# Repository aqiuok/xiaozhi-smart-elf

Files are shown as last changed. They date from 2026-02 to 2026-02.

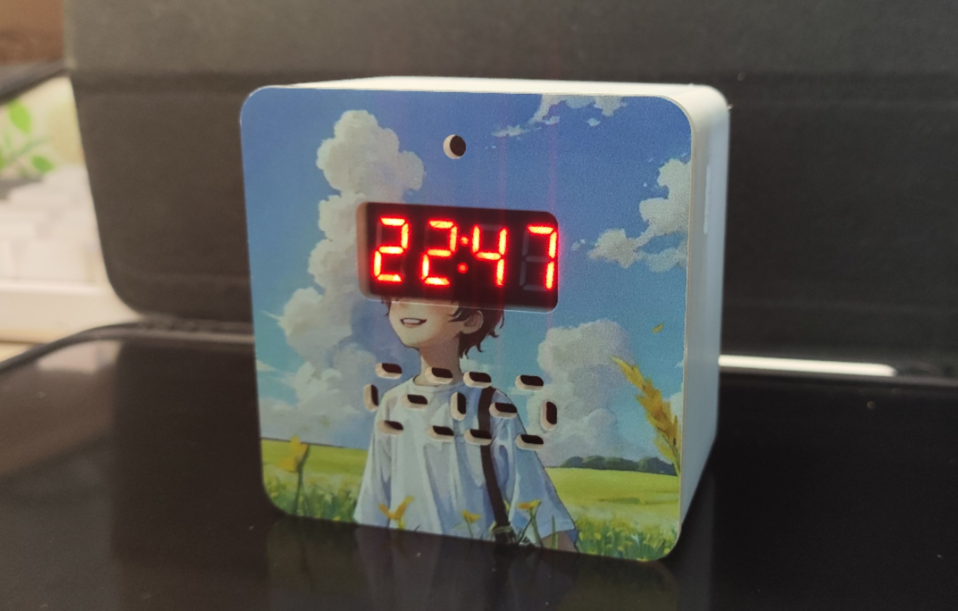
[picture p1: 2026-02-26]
photos/R5iOM2G0jZUlhVA9MYZS8TLprcBygYSpuvqxCEv5.jpeg

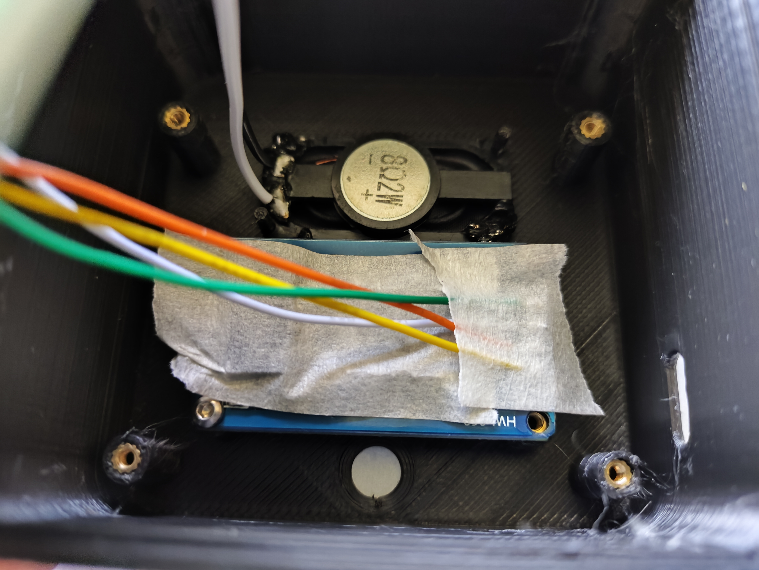
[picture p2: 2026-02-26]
photos/ceK1EityDw41dxoPptlsX2srFDPeEycVAjOOcUzq.jpeg

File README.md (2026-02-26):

### 小智精灵

##### 文件内容

小智精灵

				模块代码

								AnalogRead

								DS1302_Memory

								SimpleTime

								TM1637Test

								UART

				外壳

						小智精灵 v19.stl		（前壳）

						小智精灵 v21.stl		（后盖）

				总代码

								node1				（台灯）

								node2				（客厅灯）

								WiFiMeshv1_1  （小智精灵ESP32-C3）

								SU-03T			   （离线语音SU-03T烧录固件，烧录工具，烧录教程）

##### 	语音控制

微信截图_20230427223057						







##### 模块测试记录

光敏获取当前光照强度，其中使用ADC，

		光强：844（613mv）

		光弱：1850（1274mv）

		黑暗：4095（2853mv）

获取当前时间

						1.DS1302设置时间，其中使用到DS1302库   

数据格式：

```
10:37:50.813 -> data read (20) = "what time is it"
10:37:55.790 -> 04/11/2023 10:37:31 +
```

						2.获取网络时间，午夜12点更新时间并写入DS1302，写入前先检查是否获取到准确时间（与DS1302的时间进行对比，相差 10S内进行更新时间，否则不进行更新）    

 数据格式：

```
11:34:51.666 -> Tuesday, April 11 2023 11:34:53
```

网络时间的库获取到时间格式

```
getLocalTime(&timeinfo)；
timeinfo
```

DS1302获取时间的格式

```
RtcDateTime now = Rtc.GetDateTime();
now.Hour();
```

数码管显示，驱动芯片为TM1637，可以设置数码管的亮度，通过光敏控制此亮度

语音模块，SU-03T，通过串口来实现

```
PWM模式下，关闭电平翻转
开启：占空比100
关闭：占空比0
```

小爱同学发送的信息

```
21:27:29.147 -> MQTT接收到的主题：LED1002
21:27:29.147 -> on
21:27:29.147 -> #node1#on#

21:28:06.948 -> MQTT接收到的主题：LED1002
21:28:06.948 -> on#80
21:28:06.948 -> #node1#on#80#
```

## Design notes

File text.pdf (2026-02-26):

# 小智精灵 基于WiFi-Mesh技术的智能桌面助手

河南省青年科技人才创新创业大赛

目录

## 第 1 章 项目功能介绍

产品概述：小智精灵是一个使用Wi-Fi Mesh技术控制智能家居的桌面离线语音助手摆件。小 智精灵由于使用的是Wi-Fi Mesh技术，使得在离网时可以使用自身的语音功能进行控制智能 家居，在在网时可以通过Web、微信小程序、APP以及小爱同学进行控制，解决没有网络时无 法控制家里智能设备的痛点，同时使用应答流程来保证传输的指令得到有效的执行。小智精 灵自身带有LED灯、光敏传感器和数码管，可以通过语音来控制自身灯光，使用20KHz PWM调 光，更加护眼；数码管通过RTC时钟显示当前时间，同时使用光照传感器来智能调控数码管亮 的程度，保证数码管亮度显示温和。底部带有无线充电线圈，可以无感充电，使用更加方 便。亮点：超多设备接入，可以不接服务器使用，超安全！

（1）使用Wi-Fi Mesh技术，将智能设备通过Wi-Fi Mesh连接，多个设备只需一个设备接入网 络，减小路由器的开支。
（2）超级安全，在离网时使用，能够提供更高的安全，对不信任物联网设备安全的人提供更 急啊安全的方案。
（3）控制精准，通过应答流程来保证下达的指令都能够准确执行。 （4）多方式控制，Web、APP、微信小程序和其他物联网平台（如：小爱同学）。 （5）无网络时可以通过自带的离线语音功能来控制智能家居，无网络使用更加安全。 （6）数码管时钟显示，RTC时钟芯片保证时间准确，联网时或重启时自动校准时间。 （7）数码管的亮度根据环境来调节，显示更加柔和。
（8）无线供电，通过无线充电接受模块来实现。
（9）彩印亚克力面板，3D打印外壳，桌面级摆件。

## 第 2 章 项目框架

项目框架如图2.1所示，在项目框架中分为供电系统和功能系统两大部分，在供电系统中 主要包括锂电池的充电管理和系统的供电电路；在功能系统中包括主控模块、离线语音模块 和外设模块，外设模块包括LED、数码管、光照传感器和RTC时钟。

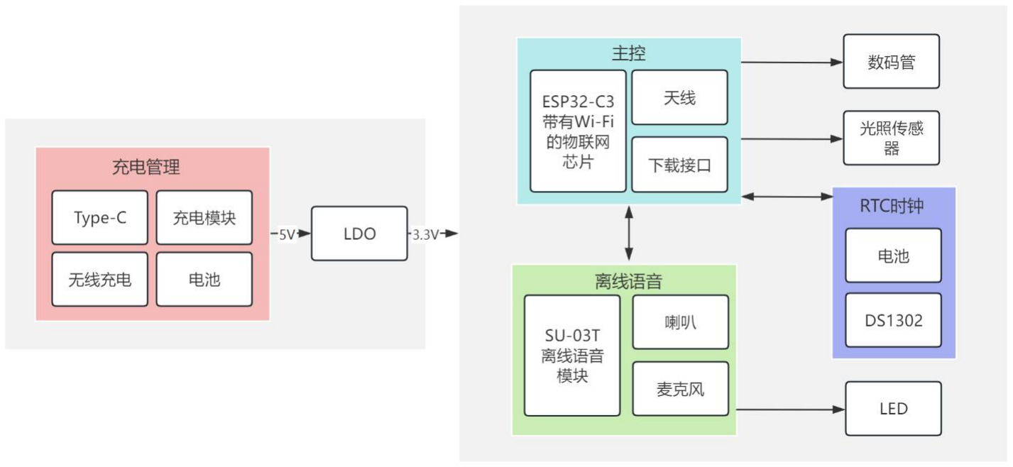
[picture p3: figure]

图 2.1

## 第 3 章 项目硬件介绍

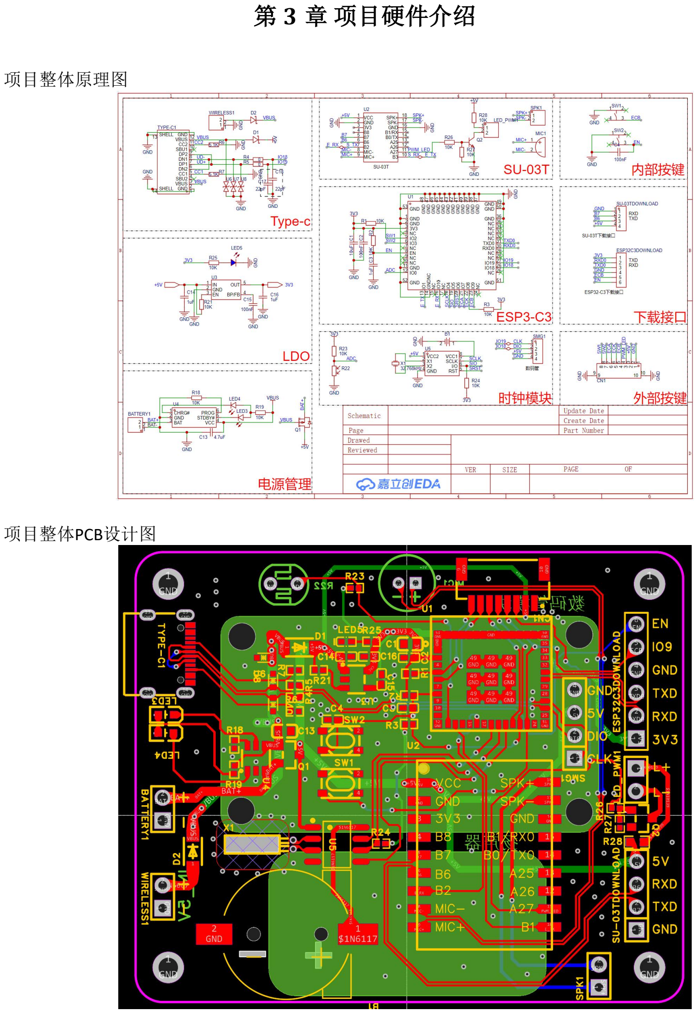
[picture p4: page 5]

项目整体原理图

项目整体PCB设计图

### 3.1 核心控制系统

核心控制系统使用ESP32-C3来进行正个系统的控制，ESP32-C3 是一款安全稳定、低功 耗、低成本的物联网芯片，搭载 RISC-V 32 位单核处理器，支持 2.4 GHz Wi-Fi 和 Bluetooth 5 (LE)，为物联网产品提供行业领先的射频性能、完善的安全机制和丰富的内存 资源。
在硬件设计中，主要包括ESP32-C3的供电电路和外围电路、数据下载接口Type-C、芯片 BOOT键和REST键。其中ESP32-C3的供电电路保证ESP32-C3能够正常运行，在发送数据时ESP32 会消耗很大的电流，这就要求ESP32的供电电路能够满足其要求，其供电电路如图3-1所示。 外围电路保证ESP32能够按照规定的时序进行上电，完成上电的初始化，如图3-2所示。数据 下载接口同时也是电池有线充电的接口，Type-C的数据直接连接到ESP32-C3内部的USB接口， 通过该USB就可以进行下载数据、更新固件等，其电路如图3-3所示。芯片BOOT键和REST键， 是为了方便开发调试使用，其硬件设计如下图3-4所示。

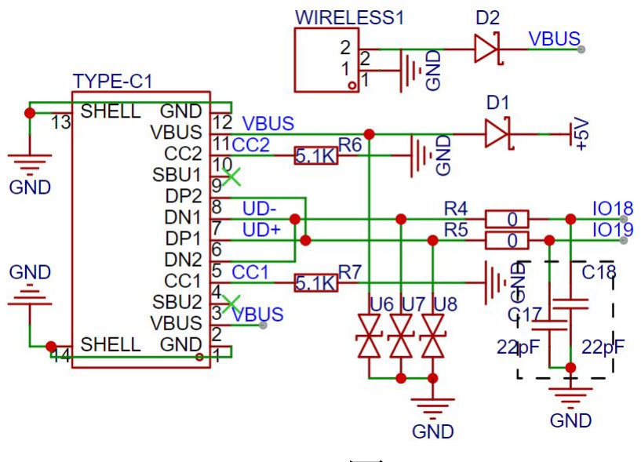
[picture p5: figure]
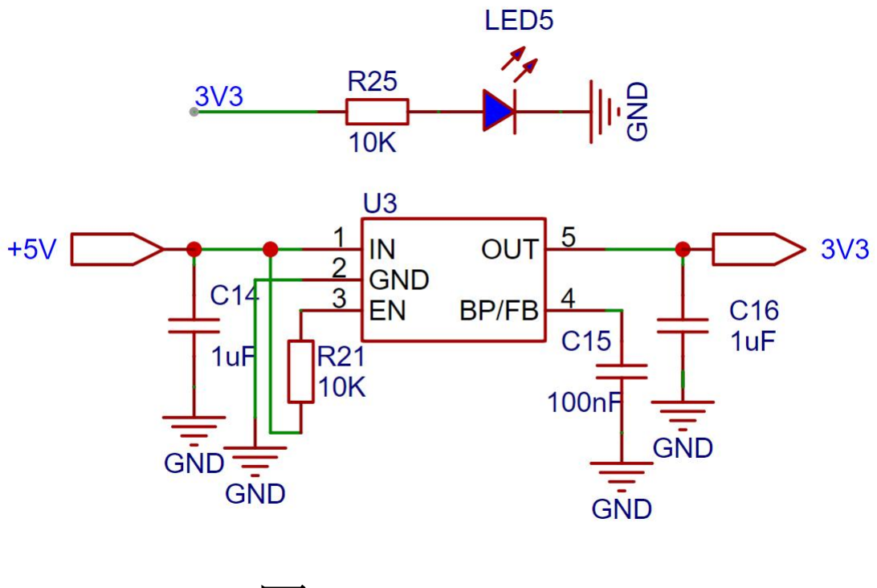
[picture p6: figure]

图3-1 | 图3-2

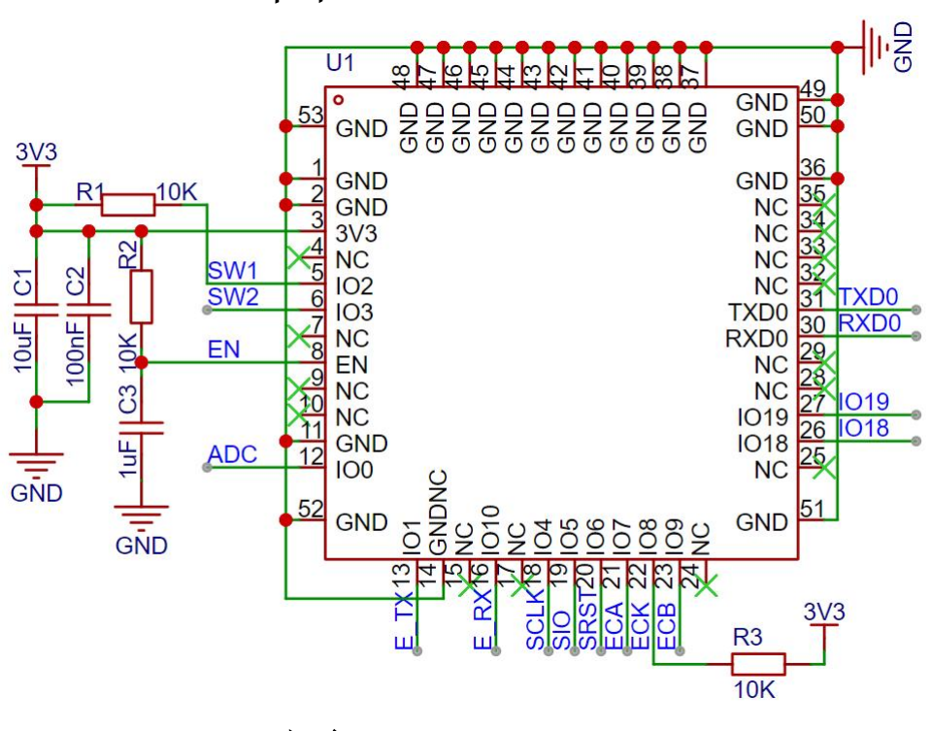
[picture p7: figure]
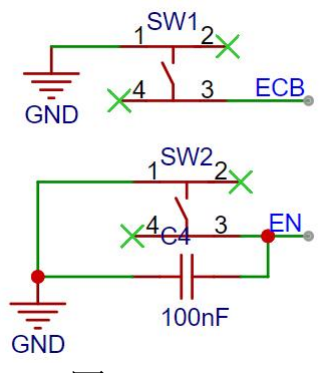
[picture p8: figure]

图3-3 | 图3-4

### 3.2 离线语音模块

离线语音模块主要包括一个SU-03T离线语音模组、扬声器和麦克风，声音通过麦克风将 音频数据传给SU-03T离线语音模组，通过自身的运算单元将音频数据进行处理，处理之后转 化成具体指令，接下来将通过UART将具体指令传给ESP32-C3，或者控制扬声器来外放声音和 控制LED。硬件设计中，只需给SU-03T模组上电、接入麦克风、扬声器即可工作，同时也需要 将其串口接到ESP32-C3的串口，以此来进行串口通信，其外围电路如图3-5所示。

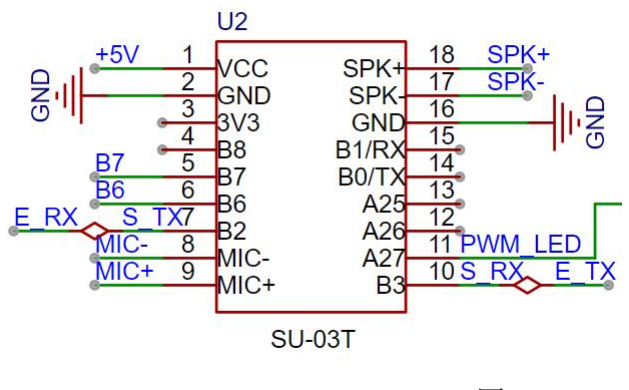
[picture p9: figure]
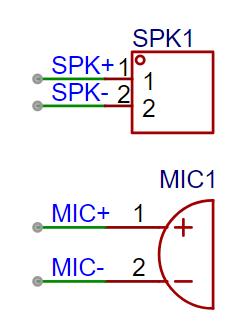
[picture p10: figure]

图3-5

### 3.3 时钟模块

时钟模块使用DS1302芯片，DS1302是涓流充电计时芯片，包含实时时钟/日历和31字节静 态RAM。它通过简单的串行接口与微处理器通信。实时时钟/日历提供秒、分、时、星期、日 期、月和年信息。在硬件设计中需要考虑其外部晶振，避免其他信号干扰，同时为了保持设 备掉电不掉时，还需要接入一颗CR1220规格的电池，DS1302于ESP32-C3进行通信，其通信方 式为变异的SPI通信方式，需要将SCLK、I/0和RST接入ESP32，其电路设计如图3-6所示。

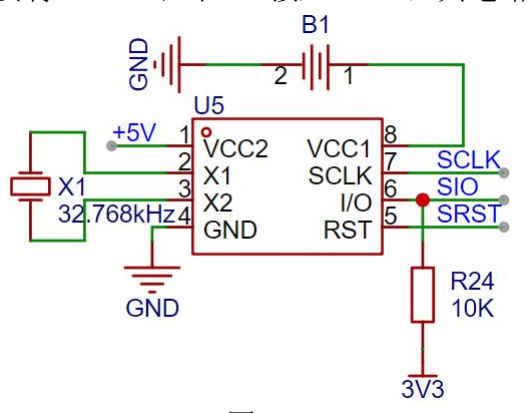
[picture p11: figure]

图3-6

### 3.4 数码管显示模块

数码管显示模块这里使用了一个TM1637芯片驱动的数码管模块，该模块的通信方式为串 行通信方式，所以只需要将信号线和数据线连接到ESP32-C3，当然其正常运行也需要供电， 其硬件设计如图3-7所示。

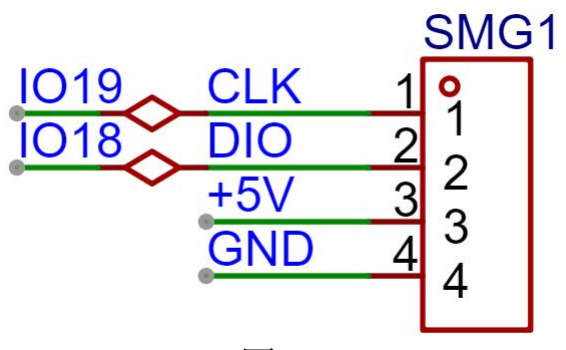
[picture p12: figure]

图3-7

### 3.5 光照传感器模块

光照传感器模块使用的是一个光敏电阻，通过和一个电阻进行串联，读取分压的电压， 通过ESP32-C3自带的ADC功能进行处理，将光照数据转化为数字，其ADC功能的分辨率为12 位。所以著需要接入到ESP32-C3的一个GPIO口上，来进行采集光照信息，从而来控制数码管 的亮度，提供柔和的时间显示。其电路设计如图3-8所示。

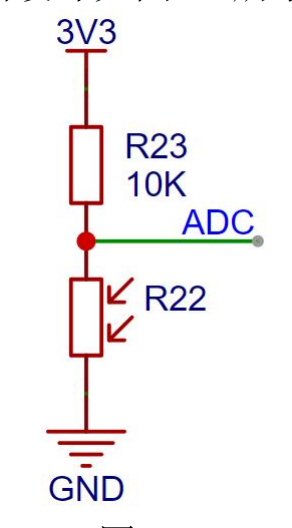
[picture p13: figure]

图3-8

## 3.6 LED 模块

LED模块是通过一个三极管S8050来进行控制，其控制方式为PWM，只需要给三极管一个 PWM波，即可控制LED的亮度和开关，其使用20KHz的PWM波，能够保护眼睛。其电路设计如图 3-9所示。

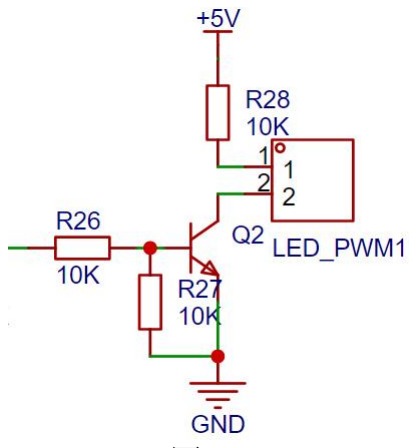
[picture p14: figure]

图3-9

### 3.7 电源管理模块

电源模块包括锂电池充电模块、无线供电模块和电源选择模块，锂电池充电使用TP4057 芯片进行实现锂电池的充电功能，这里的锂电池要求带充放电保护的锂电池。电源选择模块 使用一个MOS去实现电源选择，在没有外部电源供电时，MOS打开，使用电池供电，当有外部 电源，包括有线供电和无线供电，MOS管就会关闭，整个系统使用外部电源进行供电，同时外 部电源也会通过充电模块对锂电池进行充电。其电路设计如图3-2和图3-10所示。

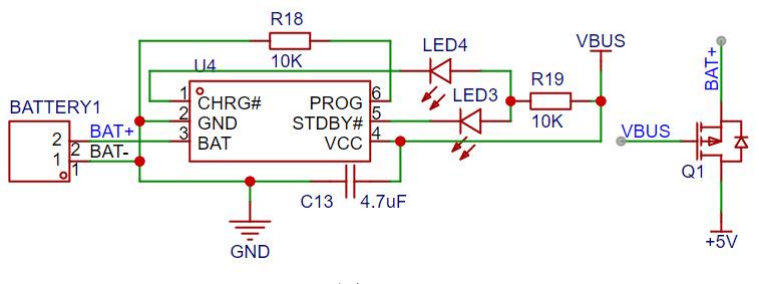
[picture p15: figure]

图 3-10

## 第 4 章 代码流程图

其代码流程图如图 4-1 所示

系统开始上电之后，先进行初始化，其初始
化包括串口初始化、Wi-Fi MESH的初始化、WiFi 的初始化、时钟的初始化、连接Wi-Fi和MQTT服务 器、连接获取时间的服务器以及实现的显示。
初始化完成后进入循环函数，首先会进行关
于WiFi-MESH的操作，包括连接新的设备，向已有 的设备发送心跳包等来完成MESH服务，之后判断
是否连接Wi-Fi，如果连接Wi-Fi则继续连接MQTT 服务器，才能监听MQTT服务器发送来的数据，如
果有数据发送，则判断数据，将数据重定义到
MESH设备上，来实现云端控制MESH设备，当没有
网络、连接不到服务器、没有接收到服务器信息
时则判断是否收到离线语音模块发送来的数据，
如果有控制MESH设备的指令，则将控制MESH设备
的信息发送到MESH设备，实现控制MESH设备的功
能。由于DS1302里的时间已经校准，此时则读取
DS1302的时间，对时间进行更新并显示到数码管
上来实现时间的显示。系统则会重复执行循环函
数里的内容，从而提供服务。

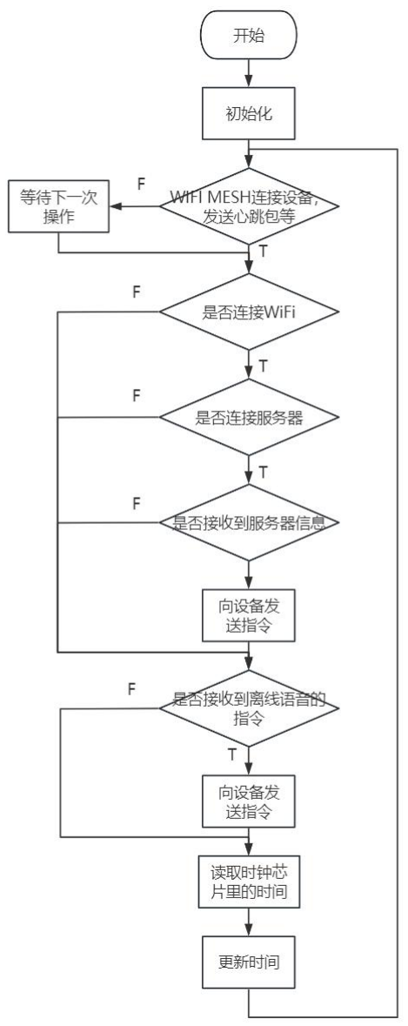
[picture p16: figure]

图 4-

## 第 5 章 项目实物图

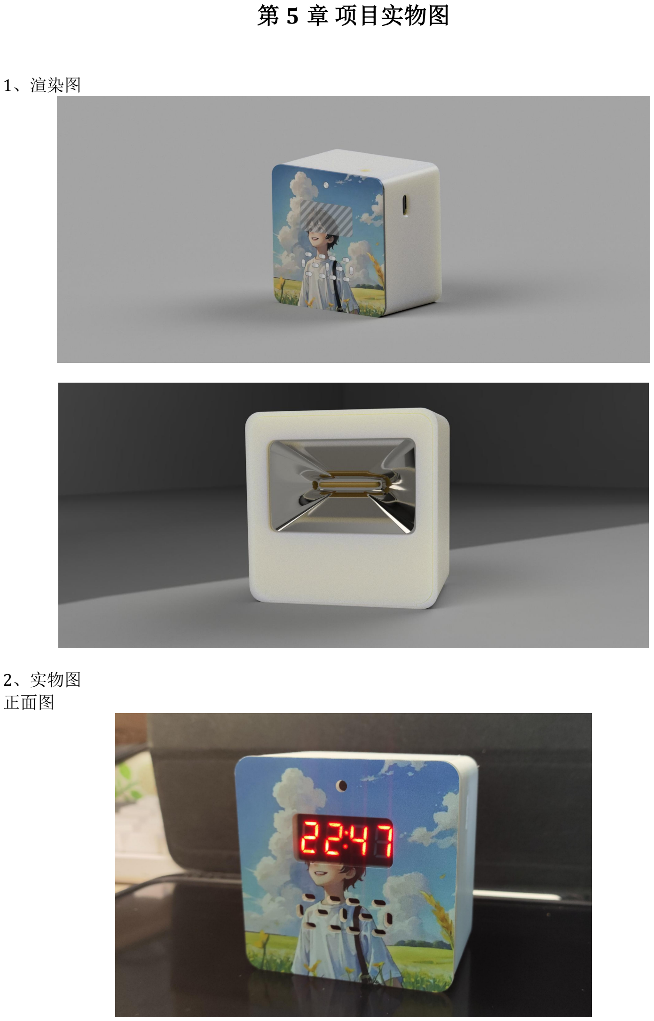
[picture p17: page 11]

1、渲染图

2、实物图

正面图

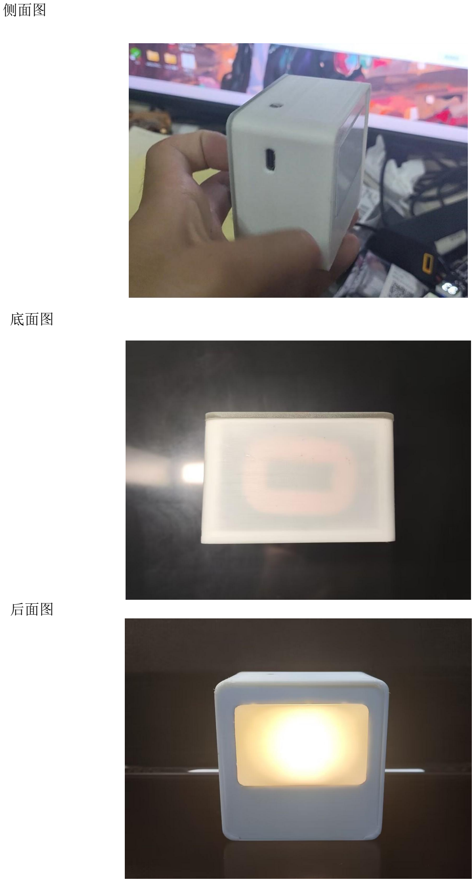
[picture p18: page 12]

侧面图

底面图

后面图

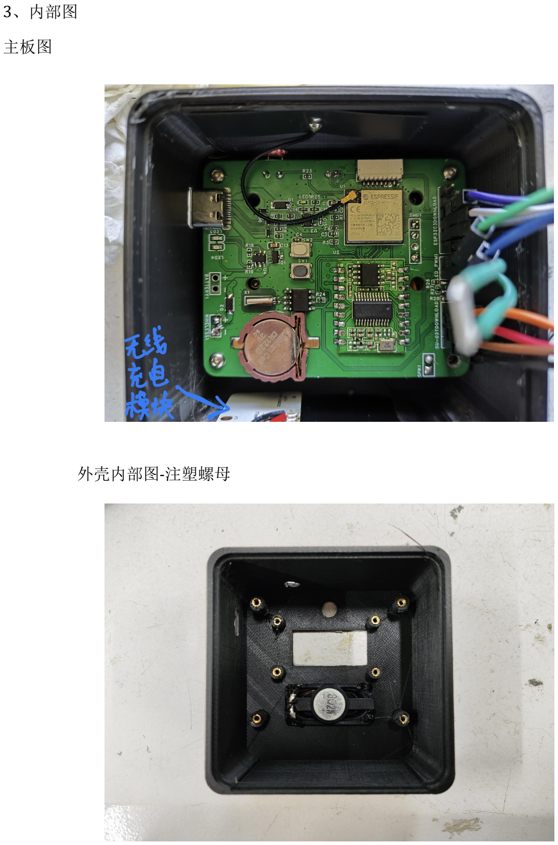
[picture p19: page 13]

3、内部图

主板图

外壳内部图-注塑螺母

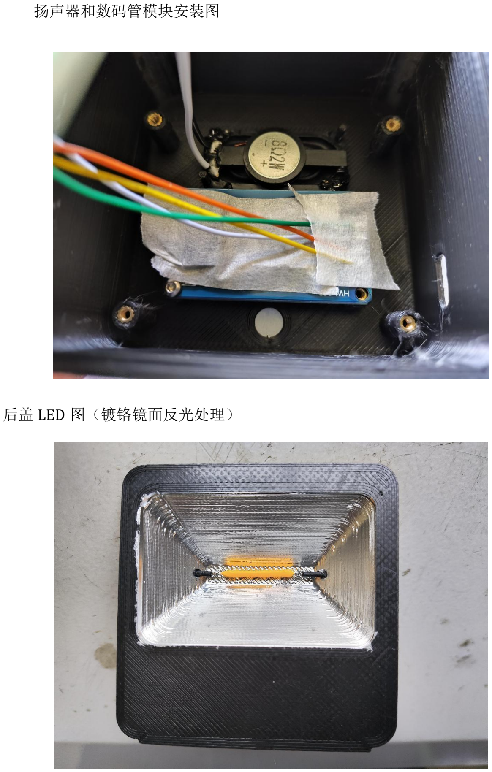
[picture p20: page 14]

扬声器和数码管模块安装图

后盖 LED 图（镀铬镜面反光处理）

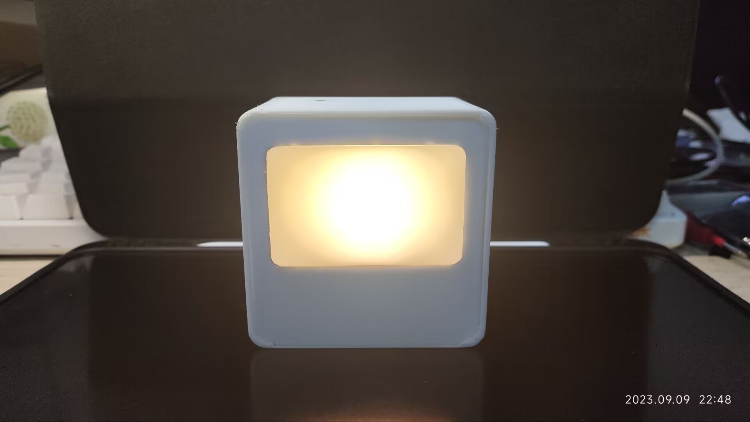
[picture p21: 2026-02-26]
photos/82997C2E23870B48F0F6F760A8A291D9.jpg

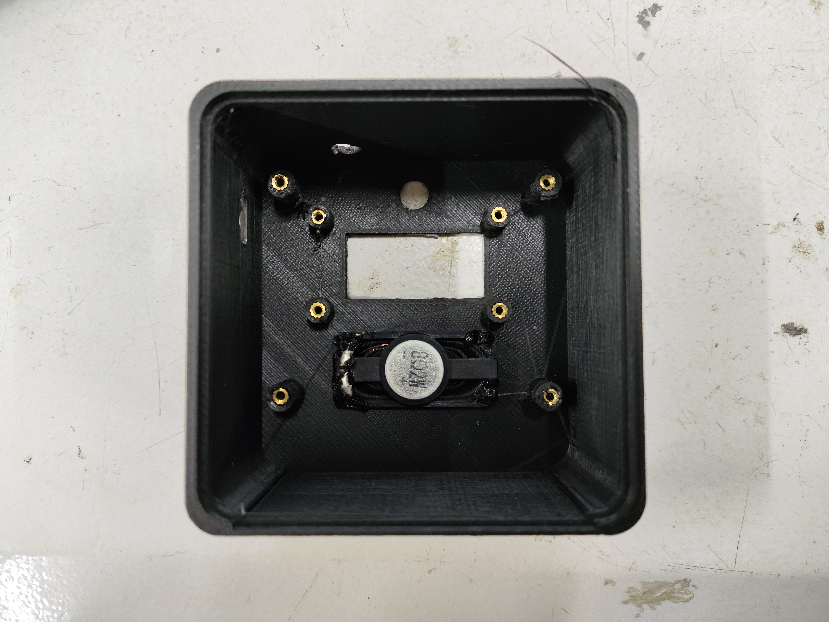
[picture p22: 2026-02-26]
photos/9ZnYbuqsTNEb2wMkbIfk8T3NcxPBOett7REhvfTZ.jpeg

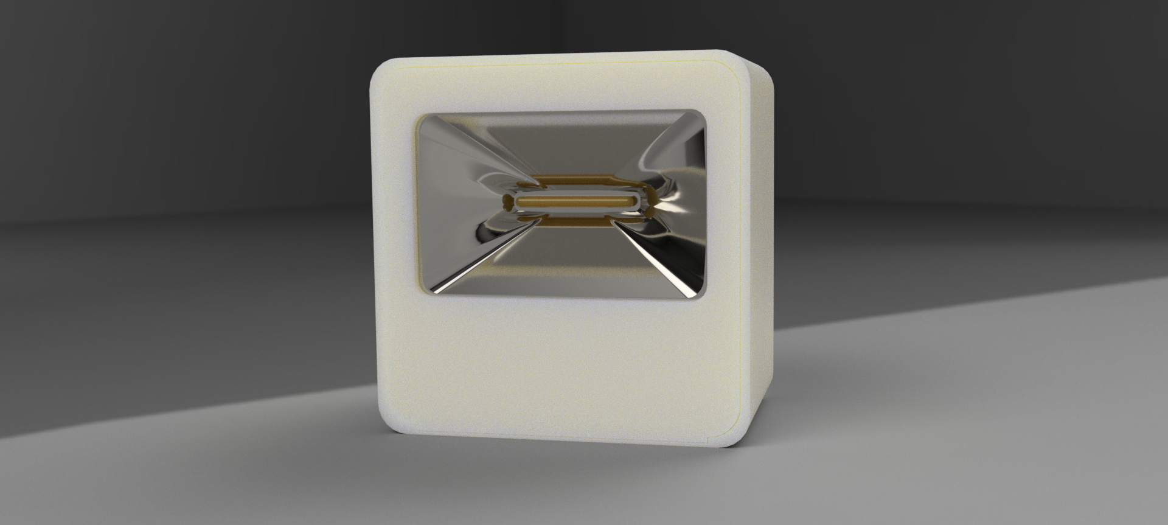
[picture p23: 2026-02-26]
photos/xcKc6k1cuOr3lsFyGagbH8heBd8prLz8wqYCjanZ.png

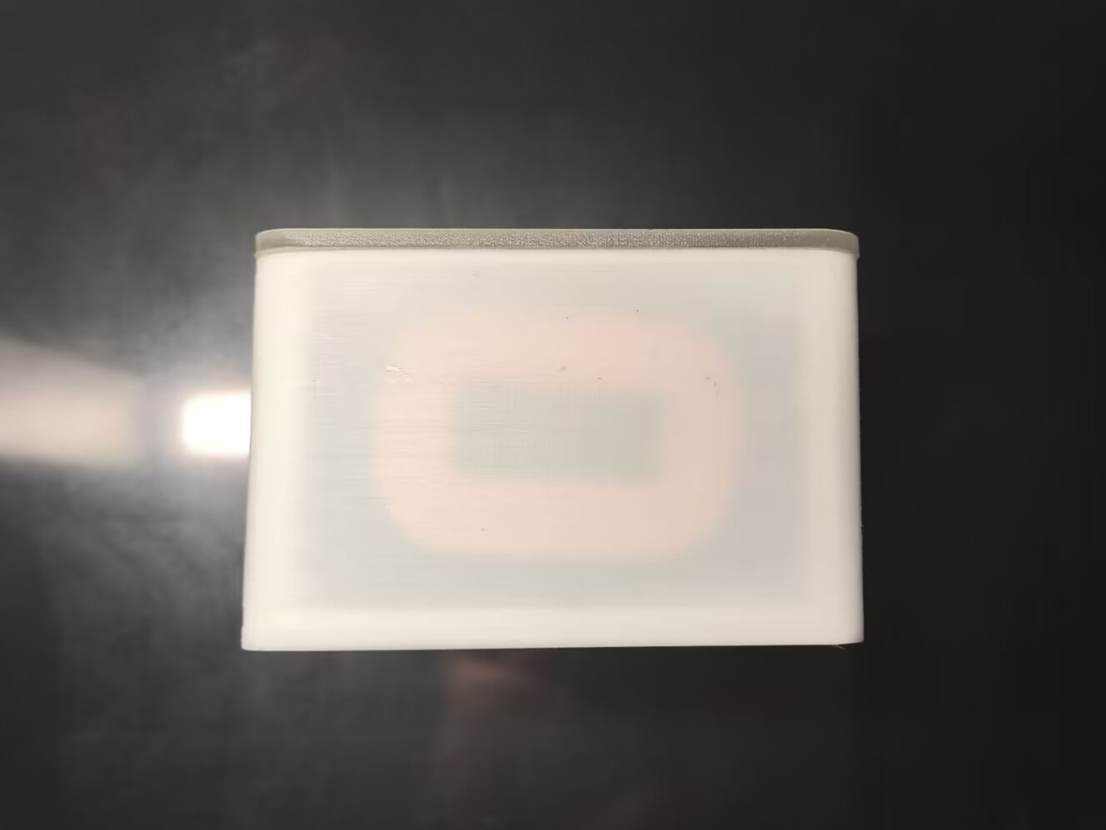
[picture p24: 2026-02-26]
photos/底面.jpg

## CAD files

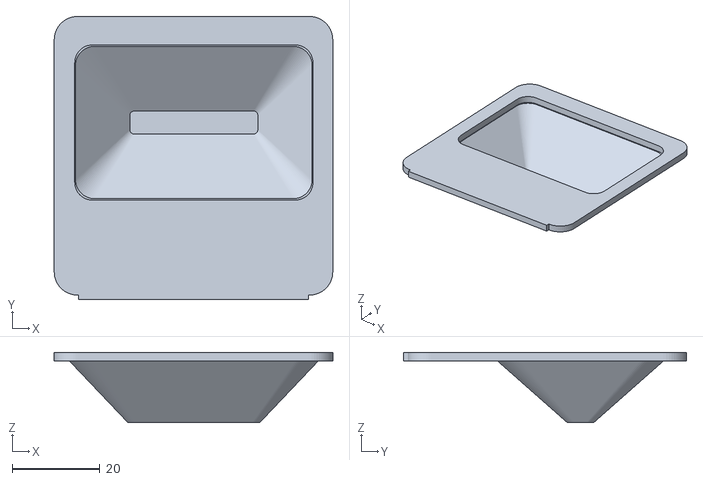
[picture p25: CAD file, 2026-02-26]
3D/小智精灵 v21.stl
63.4 x 64.4 x 16.0

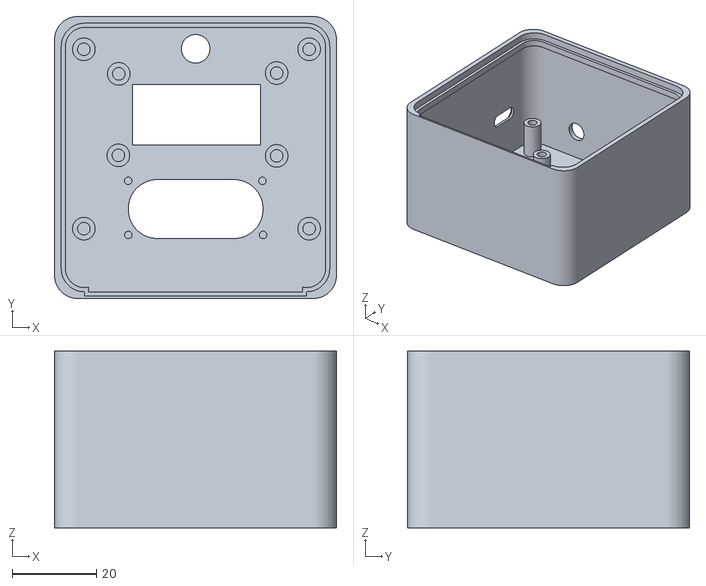
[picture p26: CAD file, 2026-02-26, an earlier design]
3D/小智精灵 v19.stl
67.0 x 67.0 x 42.0

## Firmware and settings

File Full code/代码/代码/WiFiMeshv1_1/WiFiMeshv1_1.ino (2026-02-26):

// CONNECTIONS:
// DS1302 CLK/SCLK --> 4
// DS1302 DAT/IO -->5
// DS1302 RST/CE --> 6
// DS1302 VCC --> 3.3v - 5v
// DS1302 GND --> GND

#include <WiFi.h>
#include "time.h"
#include "sntp.h"
#include <RtcDS1302.h>
#include <TM1637Display.h>
#include <Arduino.h>
#include <painlessMesh.h>
#include <PubSubClient.h>
#include <WiFiClient.h>

#define MESH_PREFIX "whateverYouLike"
#define MESH_PASSWORD "somethingSneaky"
#define MESH_PORT 5555

#define STATION_SSID "ILIVE"
#define STATION_PASSWORD "012345678"

#define HOSTNAME "MQTT_Bridge"
#define ID_MQTT "00edbb47754baafd130d211d3c351158"  //用户私钥，控制台获取

const char* topicNode1_LED = "LED1002";
const char* topicNode2_LED = "LED2002";

#define CLK 0
#define DIO 1

TM1637Display display(CLK, DIO);

// const char* ssid       = "ILIVE";
// const char* password   = "012345678";

const char* ntpServer1 = "pool.ntp.org";
const char* ntpServer2 = "time.nist.gov";
const long gmtOffset_sec = 8 * 3600;
const int daylightOffset_sec = 0;
int brightness;
const char* time_zone = "CET-1CEST,M3.5.0,M10.5.0/3";  // TimeZone rule for Europe/Rome including daylight adjustment rules (optional)
bool colon = true;
ThreeWire myWire(4, 10, 5);  // IO, SCLK, CE
RtcDS1302<ThreeWire> Rtc(myWire);
#define countof(a) (sizeof(a) / sizeof(a[0]))

const char data[] = "what time is it";
String senmsg = "";
String Node1_LED_State = "";
String Node2_LED_State = "";
struct tm timeinfo;
RtcDateTime compiled;
char str_time[12];
char str_date[12];
//时间戳
uint32_t timestamp1 = 0;  //语音发送到处理器的时间戳
uint32_t timestamp2 = 0;  //处理器发送数据的时间戳
uint32_t timestamp3 = 0;  //被控设备接收到数据的时间戳
uint32_t timestamp4 = 0;  //接收到被控设备回传消息的时间戳
// Prototypes
void receivedCallback(const uint32_t& from, const String& msg);
void mqttCallback(char* topic, byte* payload, unsigned int length);

IPAddress getlocalIP();

const char* mqtt_server = "bemfa.com";  //默认，MQTT服务器
const int mqtt_server_port = 9501;      //默认，MQTT服务器
IPAddress myIP(0, 0, 0, 0);
// IPAddress mqttBroker(192, 168, 1, 1);

painlessMesh mesh;
WiFiClient wifiClient;
PubSubClient mqttClient(mqtt_server, 9501, mqttCallback, wifiClient);

void printLocalTime() {
  struct tm timeinfo;
  if (!getLocalTime(&timeinfo)) {
    Serial.println("No time available (yet)");
    return;
  }
  Serial.println(&timeinfo, "%A, %B %d %Y %H:%M:%S");
}

// Callback function (get's called when time adjusts via NTP)
void timeavailable(struct timeval* t) {
  Serial.println("Got time adjustment from NTP!");
  printLocalTime();
}

void setup() {
  Serial.begin(115200);
  Serial1.begin(9600, SERIAL_8N1, 6, 7);
  display.setBrightness(3);
  display.showNumberDecEx(0, true);  // Expect: 0000
  analogReadResolution(12);
  //WIFIMESH
  mesh.setDebugMsgTypes(ERROR | STARTUP | CONNECTION);  // set before init() so that you can see startup messages

  // Channel set to 6. Make sure to use the same channel for your mesh and for you other
  // network (STATION_SSID)
  mesh.init(MESH_PREFIX, MESH_PASSWORD, MESH_PORT, WIFI_AP_STA, 6);
  mesh.onReceive(&receivedCallback);

  mesh.stationManual(STATION_SSID, STATION_PASSWORD);
  mesh.setHostname(HOSTNAME);

  // Bridge node, should (in most cases) be a root node. See [the wiki](https://gitlab.com/painlessMesh/painlessMesh/wikis/Possible-challenges-in-mesh-formation) for some background
  mesh.setRoot(true);
  // This node and all other nodes should ideally know the mesh contains a root, so call this on all nodes
  mesh.setContainsRoot(true);

  // set notification call-back function
  sntp_set_time_sync_notification_cb(timeavailable);

  /**
   * NTP server address could be aquired via DHCP,
   *
   * NOTE: This call should be made BEFORE esp32 aquires IP address via DHCP,
   * otherwise SNTP option 42 would be rejected by default.
   * NOTE: configTime() function call if made AFTER DHCP-client run
   * will OVERRIDE aquired NTP server address
   */
  sntp_servermode_dhcp(1);  // (optional)

  /**
   * This will set configured ntp servers and constant TimeZone/daylightOffset
   * should be OK if your time zone does not need to adjust daylightOffset twice a year,
   * in such a case time adjustment won't be handled automagicaly.
   */
  configTime(gmtOffset_sec, daylightOffset_sec, ntpServer1, ntpServer2);

  /**
   * A more convenient approach to handle TimeZones with daylightOffset 
   * would be to specify a environmnet variable with TimeZone definition including daylight adjustmnet rules.
   * A list of rules for your zone could be obtained from https://github.com/esp8266/Arduino/blob/master/cores/esp8266/TZ.h
   */
  //configTzTime(time_zone, ntpServer1, ntpServer2);
  // Serial.print("compiled: ");
  // Serial.print(__DATE__);
  // Serial.println(__TIME__);

  Rtc.Begin();
  //程序下载编译时，自动把系统时间定义进结构变量中

  compiled = RtcDateTime(__DATE__, __TIME__);

  printDateTime(compiled);
  Serial.println();
  //当发现RTC时间丢失或错乱，可以为RTC重新写入时间
  if (!Rtc.IsDateTimeValid()) {
    Serial.println("RTC lost confidence in the DateTime!");
    Rtc.SetDateTime(compiled);
  }

  if (Rtc.GetIsWriteProtected()) {
    Serial.println("RTC was write protected, enabling writing now");
    Rtc.SetIsWriteProtected(false);
  }

  if (!Rtc.GetIsRunning()) {
    Serial.println("RTC was not actively running, starting now");
    Rtc.SetIsRunning(true);
  }

  RtcDateTime now = Rtc.GetDateTime();
  if (now < compiled) {
    Serial.println("RTC is older than compile time!  (Updating DateTime)");
    Rtc.SetDateTime(compiled);
  }


  /* comment out on a second run to see that the info is stored long term */
  // Store something in memory on the RTC
  uint8_t count = sizeof(data);
  uint8_t written = Rtc.SetMemory((const uint8_t*)data, count);  // this includes a null terminator for the string
  if (written != count) {
    Serial.print("something didn't match, count = ");
    Serial.print(count, DEC);
    Serial.print(", written = ");
    Serial.print(written, DEC);
    Serial.println();
  }
  /* end of comment out section */
  // connect to WiFi
  Serial.printf("Connecting to %s ", STATION_SSID);
  WiFi.begin(STATION_SSID, STATION_PASSWORD);
  while (WiFi.status() != WL_CONNECTED) {
    delay(500);
    Serial.print(".");
  }
  if (mqttClient.connect(ID_MQTT)) {
    mqttClient.subscribe(topicNode1_LED);
    mqttClient.subscribe(topicNode2_LED);
  }
  // mqttClient.subscribe(topic_LED);

  // Serial.println(" CONNECTED");
  //获取网络时间，更新DS1302中的时间

  getLocalTime(&timeinfo);

  char str_time[12];
  strftime(str_time, sizeof(str_time), "%H:%M:%S", &timeinfo);
  //strftime(str_date, sizeof(str_date), "%B %d %Y", &timeinfo);
  //Serial.println(__DATE__);
  //Serial.println(str_date);
  compiled = RtcDateTime(__DATE__, str_time);
  Rtc.SetDateTime(compiled);
}

void loop() {
  mesh.update();
  mqttClient.loop();
  if (myIP != getlocalIP()) {
    myIP = getlocalIP();
    Serial.println("My IP is " + myIP.toString());

    if (mqttClient.connect(ID_MQTT)) {
      mqttClient.subscribe(topicNode1_LED);
      mqttClient.subscribe(topicNode2_LED);
    }
  }
  if (Serial1.available()) {  // 如果有数据可用
    String hexString = "";
    while (Serial1.available() > 0) {  // 反复读取串口直到没有为止
      byte incomingByte = Serial1.read();
      hexString += (incomingByte < 16 ? "0" : "") + String(incomingByte, HEX);  // 将字节转换为字符串表示的十六进制
    }
    timestamp1 = mesh.getNodeTime();
    Serial.print(timestamp1);
    Serial.print("  Received Hex String: ");
    Serial.println(hexString);
    //开关灯
    if (hexString == "98a30b11") {  //打开台灯
      senmsg = "#node1#on";
      mesh.sendBroadcast(senmsg);
      timestamp2 = mesh.getNodeTime();
      Serial.print(timestamp2);
      Serial.print("  ");
      Serial.println(senmsg);

    } else if (hexString == "98a30b12") {  //关闭台灯
      senmsg = "#node1#off";
      mesh.sendBroadcast(senmsg);
      timestamp2 = mesh.getNodeTime();
      Serial.print(timestamp2);
      Serial.print("  ");
      Serial.println(senmsg);

    } else if (hexString == "98a30b13") {  //台灯调亮一点
      senmsg = "#node1#up";
      mesh.sendBroadcast(senmsg);
      timestamp2 = mesh.getNodeTime();
      Serial.print(timestamp2);
      Serial.print("  ");
      Serial.println(senmsg);

    } else if (hexString == "98a30b14") {  //台灯调暗一点
      senmsg = "#node1#down";
      mesh.sendBroadcast(senmsg);
      timestamp2 = mesh.getNodeTime();
      Serial.print(timestamp2);
      Serial.print("  ");
      Serial.println(senmsg);

    } else if (hexString == "98a30bff") {  //打开所有的灯
      senmsg = "#node9#on";
      mesh.sendBroadcast(senmsg);
      timestamp2 = mesh.getNodeTime();
      Serial.print(timestamp2);
      Serial.print("  ");
      Serial.println(senmsg);

    } else if (hexString == "98a30bfe") {  //关闭所有的灯
      senmsg = "#node9#off";
      mesh.sendBroadcast(senmsg);
      timestamp2 = mesh.getNodeTime();
      Serial.print(timestamp2);
      Serial.print("  ");
      Serial.println(senmsg);

    } else if (hexString == "98a30b21") {  //打开客厅灯
      senmsg = "#node2#on";
      mesh.sendBroadcast(senmsg);
      timestamp2 = mesh.getNodeTime();
      Serial.print(timestamp2);
      Serial.print("  ");
      Serial.println(senmsg);

    } else if (hexString == "98a30b22") {  //关闭客厅灯
      senmsg = "#node2#off";
      mesh.sendBroadcast(senmsg);
      timestamp2 = mesh.getNodeTime();
      Serial.print(timestamp2);
      Serial.print("  ");
      Serial.println(senmsg);
    }
  }

  int analogValue = analogRead(3);
  // Serial.println(analogValue);
  if (analogValue >= 1300)
    brightness = 1;
  else if (analogValue < 1300 && analogValue >= 1100)
    brightness = 2;
  else if (analogValue < 1100 && analogValue >= 900)
    brightness = 3;
  else if (analogValue < 900 && analogValue >= 700)
    brightness = 4;
  else if (analogValue < 700)
    brightness = 5;
  display.setBrightness(brightness);
  // Serial.println(brightness);
  //GetDateTime函数获取RTC模块时间
  RtcDateTime now = Rtc.GetDateTime();
  printDateTime(now);

  if (!now.IsValid()) {
    // Common Causes:
    //    1) the battery on the device is low or even missing and the power line was disconnected
    Serial.println("RTC lost confidence in the DateTime!");
  }
  colon = !colon;
  int bits = colon ? 0b01000000 : 0;
  display.showNumberDecEx(now.Hour() * 100 + now.Minute(), bits, true, 4, 0);
  delay(500);
  colon = !colon;
  bits = colon ? 0b01000000 : 0;
  display.showNumberDecEx(now.Hour() * 100 + now.Minute(), bits, true, 4, 0);
  delay(500);
  // if(now.Hour()==0 && now.Minute()==0 && now.Second()==0) {
  //   getLocalTime(&timeinfo);
  //   strftime(str_time, sizeof(str_time), "%H:%M:%S", &timeinfo);
  //   strftime(str_date, sizeof(str_date), "%B %d %Y", &timeinfo);
  //   compiled = RtcDateTime(str_date, str_time);
  //   Rtc.SetDateTime(compiled);
  // }
  //printLocalTime();     // it will take some time to sync time :)
}

void printDateTime(const RtcDateTime& dt) {
  char datestring[20];

  snprintf_P(datestring,
             countof(datestring),
             PSTR("%02u/%02u/%04u %02u:%02u:%02u"),
             dt.Month(),
             dt.Day(),
             dt.Year(),
             dt.Hour(),
             dt.Minute(),
             dt.Second());
  // Serial.print(datestring);
  // Serial.println("");
}
void receivedCallback(const uint32_t& from, const String& msg) {
  timestamp4 = mesh.getNodeTime();
  Serial.print(timestamp4);
  Serial.print("  ");
  Serial.printf("bridge: Received from %u msg=%s\n", from, msg.c_str());
  String topic = "painlessMesh/from/" + String(from);
  mqttClient.publish(topic.c_str(), msg.c_str());
  String msgtopic = msg.substring(1, 6);
  //Serial.println(msg);
  //Serial.println(msgtopic);
  String str = msg;
  //Serial.println(str);
  str = str.substring(7);
  int index;
  index = str.indexOf("#");
  String str1 = str.substring(0, index);

  Serial.println(str1);
  //LED开关
  if (msgtopic == "node1") {
    //LED开关 str1
    if (Node1_LED_State != str1) {  //灯状态改变的时候才发送
      mqttClient.publish(topicNode1_LED, str1.c_str());
      //Serial.print("灯状态已改变：");
      //Serial.println(str1);
      Node1_LED_State = str1;
    }
  }
  //灯开关
  else if (msgtopic == "node2") {
    //LED开关 str1
    if (Node2_LED_State != str1) {  //灯状态改变的时候才发送
      mqttClient.publish(topicNode2_LED, str1.c_str());
      //Serial.print("灯状态已改变：");
      //Serial.println(str1);
      Node2_LED_State = str1;
    }
  }
  //时间戳计算
  String str_TIME = msg;
  int index_TIME = str_TIME.indexOf("#");
  String msgtopic_TIME = str_TIME.substring(0, index_TIME);
  String timestamp = str_TIME.substring(index_TIME + 1);
  // Serial.println("Data:");
  //Serial.print(msgtopic_TIME);
  //   Serial.println(" ");
  //Serial.println(timestamp3);
  if (msgtopic_TIME == "TIME") {
    //Serial.print("timestamp = ");
    //Serial.println(timestamp);
    int timestamp1 = timestamp.toInt();
    uint32_t timestamp3 = (uint32_t)timestamp1;
    //Serial.print("timestamp3 = ");
    //Serial.println(timestamp3);
    /* 
    //时间戳
uint32_t timestamp1 = 0;  //语音发送到处理器的时间戳
uint32_t timestamp2 = 0;  //控制设备发送数据的时间戳
uint32_t timestamp3 = 0;  //被控设备接收到数据的时间戳
uint32_t timestamp4 = 0;  //接收到被控设备回传消息的时间戳
    */
    //语音到被控设备发送数据的时间
    Serial.println("时间戳的差     时间差");
    uint32_t Time1 = timestamp2 - timestamp1;
    uint32_t differenceTime1 = Time1 / 1000;
    Serial.println("语音到被控设备发送数据的时间");
    Serial.print(Time1);
    Serial.print("     ");
    Serial.println(differenceTime1);
    //控制设备发送数据到被控设备的时间
    uint32_t Time2 = timestamp3 - timestamp2;
    uint32_t differenceTime2 = Time2 / 1000;
    Serial.println("控制设备发送数据到被控设备的时间");
    Serial.print(Time2);
    Serial.print("     ");
    Serial.println(differenceTime2);
    //被控设备接收到数据到控制设备接收到回调信息的时间
    uint32_t Time3 = timestamp4 - timestamp3;
    uint32_t differenceTime3 = Time3 / 1000;
    Serial.println("被控设备接收到数据到控制设备接收到回调信息的时间");
    Serial.print(Time3);
    Serial.print("     ");
    Serial.println(differenceTime3);
    //带消息确认的整个流程的时间
    uint32_t Time4 = timestamp4 - timestamp1;
    uint32_t differenceTime4 = Time4 / 1000;
    Serial.println("带消息确认的整个流程的时间");
    Serial.print(Time4);
    Serial.print("     ");
    Serial.println(differenceTime4);
  }
}

void mqttCallback(char* topic, uint8_t* payload, unsigned int length) {
  char* cleanPayload = (char*)malloc(length + 1);
  memcpy(cleanPayload, payload, length);
  cleanPayload[length] = '\0';
  String msg = String(cleanPayload);
  free(cleanPayload);

  String targetStr = String(topic);  //.substring(16)
  Serial.print("MQTT接收到的主题：");
  Serial.println(targetStr);
  Serial.println(msg);
  //节点一
  if (targetStr == topicNode1_LED) {
    // Serial.println(msg);
    // if(msg == "on") {
    //   digitalWrite(12,HIGH);
    // }
    // else if(msg == "off") {
    //   digitalWrite(12,LOW);
    //   Serial.println("I m o K !");
    // }
    String senmsg = "#node1#" + msg;
    Serial.println(senmsg);
    mesh.sendBroadcast(senmsg);
  }
  //节点二//灯开关#电机开关#光敏数值
  else if (targetStr == topicNode2_LED) {
    Serial.println(msg);
    if (msg == "on") {
      digitalWrite(12, HIGH);
      // LCD_LED2 = "on";
    } else if (msg == "off") {
      digitalWrite(12, LOW);
      //Serial.println("I m o K 2 !");
      // LCD_LED2 = "off";
    }
    String senmsg = "#node2#" + msg;
    Serial.println(senmsg);
    mesh.sendBroadcast(senmsg);
  }
}

IPAddress getlocalIP() {
  return IPAddress(mesh.getStationIP());
}

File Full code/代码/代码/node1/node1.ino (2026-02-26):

//************************************************************
// this is a simple example that uses the painlessMesh library
//
// 1. sends a silly message to every node on the mesh at a random time between 1 and 5 seconds
// 2. prints anything it receives to Serial.print
//
//
//************************************************************
//这是一个台灯
#include "painlessMesh.h"

#define MESH_PREFIX "whateverYouLike"
#define MESH_PASSWORD "somethingSneaky"
#define MESH_PORT 5555

// use first channel of 16 channels (started from zero)
#define LEDC_CHANNEL_0 0

// use 12 bit precission for LEDC timer
#define LEDC_TIMER_12_BIT 12

// use 5000 Hz as a LEDC base frequency
#define LEDC_BASE_FREQ 5000

// fade LED PIN (replace with LED_BUILTIN constant for built-in LED)
#define LED_PIN 5
int brightness = 0;  // how bright the LED is

Scheduler userScheduler;  // to control your personal task
painlessMesh mesh;
uint32_t timestamp3 = 0;  //接收到信息的时间戳
// User stub
void sendMessage();  // Prototype so PlatformIO doesn't complain

Task taskSendMessage(TASK_SECOND * 1, TASK_FOREVER, &sendMessage);

void ledcAnalogWrite(uint8_t channel, uint32_t value, uint32_t valueMax = 255) {
  // calculate duty, 4095 from 2 ^ 12 - 1
  uint32_t duty = (4095 / valueMax) * min(value, valueMax);

  // write duty to LEDC
  ledcWrite(channel, duty);
}

void sendMessage() {
  String msg = "Hello from node ";
  msg += mesh.getNodeId();
  mesh.sendBroadcast(msg);
  taskSendMessage.setInterval(random(TASK_SECOND * 1, TASK_SECOND * 5));
}

// Needed for painless library
void receivedCallback(uint32_t from, String &msg) {
  timestamp3 = mesh.getNodeTime();
  Serial.print(timestamp3);
  Serial.print("  ");
  Serial.printf("startHere: Received from %u msg=%s\n", from, msg.c_str());
  String msgtopic = msg.substring(1, 6);
  Serial.print("msgtopic:");
  Serial.println(msgtopic);
  if (msgtopic == "node1") {
    msg = msg.substring(7);
    Serial.print("msg:");
    Serial.println(msg);
    int index1 = msg.indexOf("#");
    Serial.print("index1:");
    Serial.println(index1);
    if (index1 < 0) {
      if (msg == "on") {
        brightness = 200;
        ledcAnalogWrite(LEDC_CHANNEL_0, brightness);
      } else if (msg == "off") {
        brightness = 0;
        ledcAnalogWrite(LEDC_CHANNEL_0, brightness);
      } else if (msg == "up") {
        brightness += 50;
        if (brightness > 255) {
          brightness = 255;
        }
        ledcAnalogWrite(LEDC_CHANNEL_0, brightness);
      } else if (msg == "down") {
        brightness -= 50;
        if (brightness < 0) {
          brightness = 0;
        }
        ledcAnalogWrite(LEDC_CHANNEL_0, brightness);
      }
      String senmsg = "TIME";
      senmsg = senmsg + "#" +timestamp3;
      Serial.println(senmsg);
      mesh.sendBroadcast(senmsg);   //接受数据的时间
    } else {
      Serial.print("light1:");
      Serial.println(msg.substring(index1 + 1));
      brightness = map(msg.substring(index1 + 1).toInt(), 0, 100, 0, 255);  // how bright the LED is
      Serial.print("light2:");
      Serial.println(brightness);
      ledcAnalogWrite(LEDC_CHANNEL_0, brightness);
    }
  } else if (msgtopic == "node9") {
    msg = msg.substring(7);
    Serial.print("msg:");
    Serial.println(msg);
    if (msg == "on") {
      brightness = 200;
      ledcAnalogWrite(LEDC_CHANNEL_0, brightness);
    } else if (msg == "off") {
      brightness = 0;
      ledcAnalogWrite(LEDC_CHANNEL_0, brightness);
    }
  }
}

void newConnectionCallback(uint32_t nodeId) {
  Serial.printf("--> startHere: New Connection, nodeId = %u\n", nodeId);
}

void changedConnectionCallback() {
  Serial.printf("Changed connections\n");
}

void nodeTimeAdjustedCallback(int32_t offset) {
  Serial.printf("Adjusted time %u. Offset = %d\n", mesh.getNodeTime(), offset);
}

void setup() {
  Serial.begin(115200);

  // Setup timer and attach timer to a led pin
  ledcSetup(LEDC_CHANNEL_0, LEDC_BASE_FREQ, LEDC_TIMER_12_BIT);
  ledcAttachPin(LED_PIN, LEDC_CHANNEL_0);
  ledcAnalogWrite(LEDC_CHANNEL_0, 0);
  //mesh.setDebugMsgTypes( ERROR | MESH_STATUS | CONNECTION | SYNC | COMMUNICATION | GENERAL | MSG_TYPES | REMOTE ); // all types on
  mesh.setDebugMsgTypes(ERROR | STARTUP);  // set before init() so that you can see startup messages

  mesh.init(MESH_PREFIX, MESH_PASSWORD, &userScheduler, MESH_PORT, WIFI_AP_STA, 6);
  mesh.onReceive(&receivedCallback);
  mesh.onNewConnection(&newConnectionCallback);
  mesh.onChangedConnections(&changedConnectionCallback);
  mesh.onNodeTimeAdjusted(&nodeTimeAdjustedCallback);

  userScheduler.addTask(taskSendMessage);
  taskSendMessage.enable();
}

void loop() {
  // it will run the user scheduler as well
  mesh.update();
}

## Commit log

2026-02-26 initial commit:小智精灵项目
    [小智精灵 v19.stl, 小智精灵 v21.stl]
2026-02-26 文件名称修改
    [小智精灵 v19.stl, 小智精灵 v21.stl]
2026-02-26 添加readme文件
